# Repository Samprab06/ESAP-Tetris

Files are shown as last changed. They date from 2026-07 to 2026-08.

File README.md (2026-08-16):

# ESAP Tetris

A complete, feature-packed Tetris game implementation for the ESP32 microcontroller featuring a custom PCB design, real-time graphics rendering on an ILI9341 SPI TFT display, I2S audio playback, SD card asset loading and a future multiplayer implementation

---

##  PCB Design

The project features a custom-designed PCB tailored for handheld gameplay with optimized power delivery, hardware debouncing, and an auto-programming USB-C interface.

### Board Renders

| Back View (Component Side) | Front View (Controls) |
| :---: | :---: |
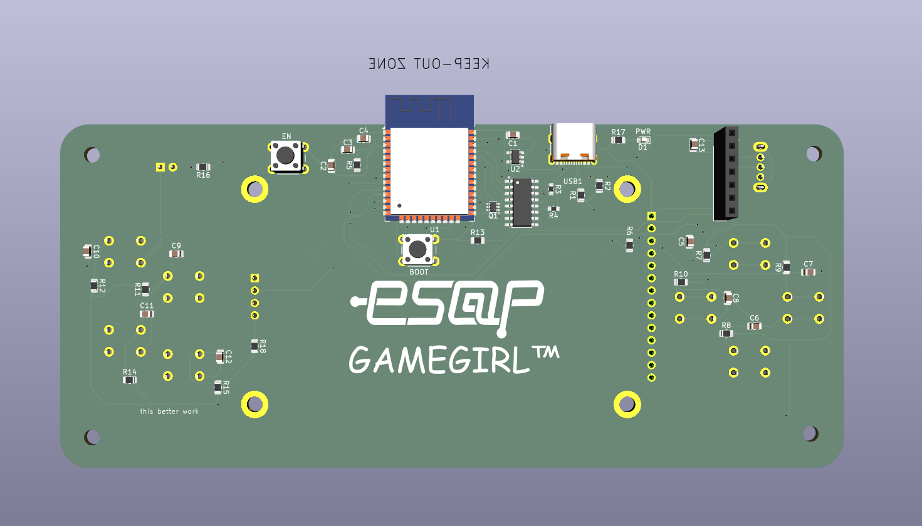
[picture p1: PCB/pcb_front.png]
PCB Front Render
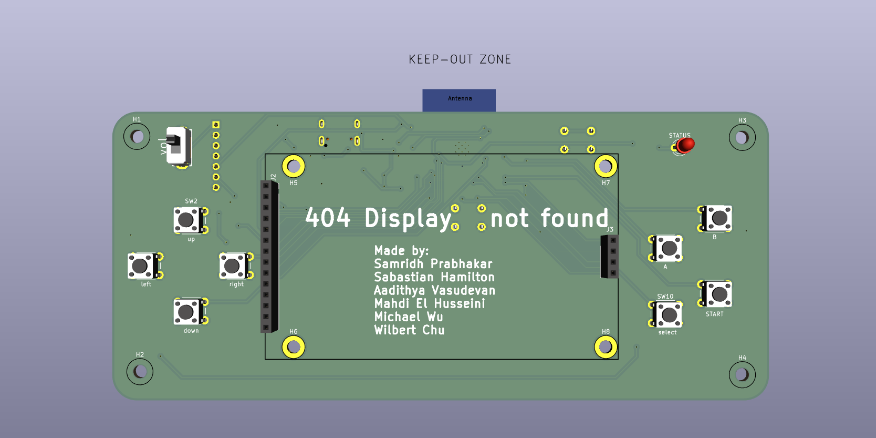
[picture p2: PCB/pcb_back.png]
PCB Back Render
|  |  |

### Key Hardware & Schematic Highlights

- **Microcontroller**: ESP32-WROOM-32 module (32-bit dual-core Xtensa @ 240 MHz, 520 KB SRAM, Wi-Fi/BT).
- **USB-C Interface & Auto-Flashing**: Integrated `CH340C` USB-to-UART converter with dual NPN auto-reset circuitry (`MUN5211DW1`) for seamless hands-free code uploads via USB Type-C.
- **Power Management**: `AP2112K-3.3` LDO regulator supplying up to 600mA at 3.3V with dedicated ground plane thermal heat sinking. USB Type-C `CC1`/`CC2` 5.1kΩ pull-down resistors for 5V C-to-C charger support.
- **Display Connection**: Dedicated 14-pin socket header for 2.8" ILI9341 SPI TFT Display (240×320 resolution) on the `VSPI` bus. Includes 10kΩ pull-up resistor on `CS` (`GPIO5`).
- **SD Card Storage**: 4-pin SPI socket header for MicroSD card module on the `HSPI` bus. Includes 10kΩ pull-up resistor on `CS` (`GPIO15`).
- **Input Controllers**: 8 tactile pushbuttons (UP, DOWN, LEFT, RIGHT, A, B, START, SELECT) with hardware RC debouncing filters (0.1µF capacitors) and 10kΩ pull-up resistors on input-only GPIOs (34, 35, 36, 39).
- **Audio & Volume Control**: Audio output header with an integrated slide switch (`SW12`) for hardware gain/volume control.

---

## 🛠️ Hardware Specifications & Pinout

### SPI Display Connection (VSPI)

| ESP32 Pin | Signal Name | Display Function |
| :--- | :--- | :--- |
| **GPIO 23** | `MOSI` | Serial Data Input |
| **GPIO 19** | `MISO` | Serial Data Output |
| **GPIO 18** | `SCK` | Serial Clock |
| **GPIO 5** | `CS` | Chip Select (10kΩ Pull-Up) |
| **GPIO 2** | `DC` | Data / Command Select |
| **GPIO 4** | `RST` | Reset |
| **3.3V** | `LED` | Display Backlight Power |

### MicroSD Card Connection (HSPI)

| ESP32 Pin | Signal Name | SD Card Function |
| :--- | :--- | :--- |
| **GPIO 13** | `MOSI` | Data Input |
| **GPIO 17** | `MISO` | Data Output |
| **GPIO 14** | `SCK` | Clock |
| **GPIO 15** | `CS` | Chip Select (10kΩ Pull-Up) |

### Game Control Buttons

| GPIO Pin | Function | Hardware Circuit |
| :--- | :--- | :--- |
| **GPIO 36 (VP)** | Left | 10kΩ Pull-Up + 0.1µF Debounce |
| **GPIO 39 (VN)** | Right | 10kΩ Pull-Up + 0.1µF Debounce |
| **GPIO 34** | Down | 10kΩ Pull-Up + 0.1µF Debounce |
| **GPIO 35** | Up / Rotate | 10kΩ Pull-Up + 0.1µF Debounce |
| **GPIO 32** | Button A | 10kΩ Pull-Up + 0.1µF Debounce |
| **GPIO 33** | Button B | 10kΩ Pull-Up + 0.1µF Debounce |
| **GPIO 27** | Start | 10kΩ Pull-Up + 0.1µF Debounce |
| **GPIO 16** | Select | 10kΩ Pull-Up + 0.1µF Debounce |

---

##  Software Architecture

The software is structured as a **PlatformIO** project 

```
ESAP_Tetris/
├── PCB/                     # KiCad 10 PCB schematics, board layouts & gerbers
│   ├── pcb_front.png
│   └── pcb_back.png
├── include/                 # Header files
│   ├── main.hpp
│   ├── logic.h
│   ├── display.h
│   ├── audio.h
│   └── sdcard.h
├── src/                     # Source implementations
│   ├── main.cpp             # FreeRTOS task initialization & main loop
│   ├── logic.cpp            # Tetris game rules & state machine
│   ├── display.cpp          # TFT graphics rendering
│   ├── audio.cpp            # I2S audio decoding & streaming
│   └── sdcard.cpp           # SD card file system interface
├── platformio.ini           # PlatformIO configuration
└── README.md                # Project documentation
```

---

##  Building & Flashing

### Prerequisites
- **VS Code** with **PlatformIO IDE** extension installed.

### Steps
1. Clone the repository:
   ```bash
   git clone https://github.com/Samprab06/ESAP-Tetris.git
   cd ESAP-Tetris
   ```
2. Connect your ESP32 board via USB-C.
3. Build & Upload firmware using PlatformIO:
   ```bash
   pio run -t upload
   ```
4. Open the Serial Monitor:
   ```bash
   pio device monitor
   ```

---

---

##  License

This project is open-source and provided for educational and personal use.

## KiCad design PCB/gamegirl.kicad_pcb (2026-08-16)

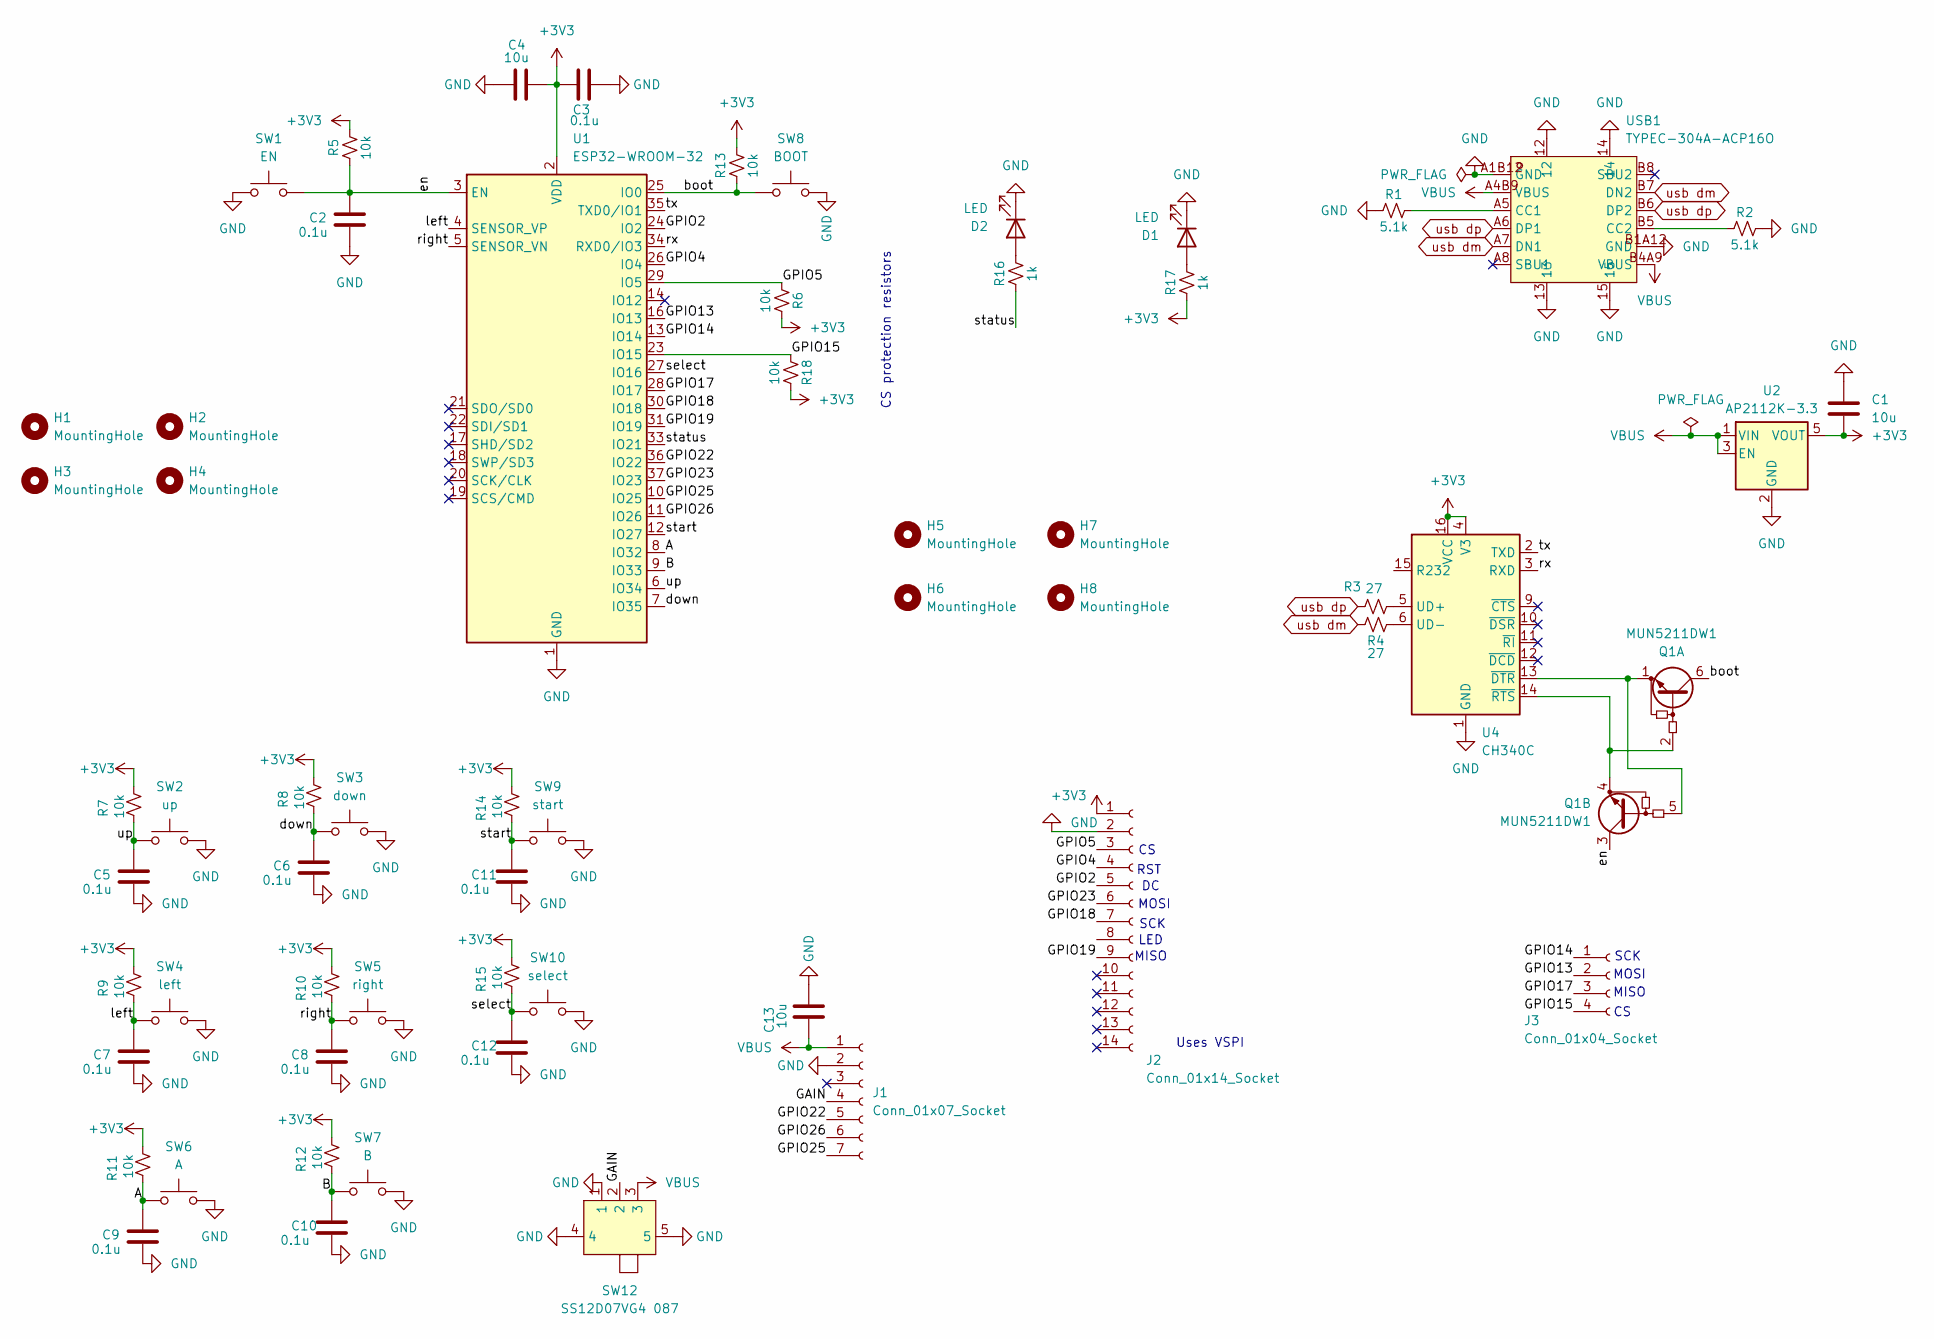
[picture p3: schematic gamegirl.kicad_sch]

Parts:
C1, C4, C13: 10u; C_0805_2012Metric
C2, C3, C5, C6, C7, C8, C9, C10, C11, C12: 0.1u; C_0805_2012Metric
D1, D2: LED; LED_0603_1608Metric
H1, H2, H3, H4: MountingHole; MountingHole_3.2mm_M3
H5, H6, H7, H8: MountingHole; MountingHole_3.2mm_M3_DIN965_Pad
J1: Conn_01x07_Socket; PinSocket_1x07_P2.54mm_Vertical
J2: Conn_01x14_Socket; PinSocket_1x14_P2.54mm_Vertical
J3: Conn_01x04_Socket; PinSocket_1x04_P2.54mm_Vertical
Q1: MUN5211DW1; SOT-363_SC-70-6
R1, R2: 5.1k; R_0805_2012Metric
R3, R4: 27; R_0603_1608Metric
R5, R6, R7, R8, R9, R10, R11, R12, R13, R14, R15, R18: 10k; R_0805_2012Metric
R16, R17: 1k; R_0805_2012Metric
SW1: EN; SW_PUSH_6mm
SW2: up; SW_PUSH_6mm
SW3: down; SW_PUSH_6mm
SW4: left; SW_PUSH_6mm
SW5: right; SW_PUSH_6mm
SW6: A; SW_PUSH_6mm
SW7: B; SW_PUSH_6mm
SW8: BOOT; SW_PUSH_6mm
SW9: start; SW_PUSH_6mm
SW10: select; SW_PUSH_6mm
SW12: SS12D07VG4 087; SW-TH_SS12D07VG4; MPN SS12D07VG4 087; LCSC Part C2939726
U1: ESP32-WROOM-32
U2: AP2112K-3.3; SOT-23-5
U4: CH340C; SOIC-16_3.9x9.9mm_P1.27mm
USB1: TYPEC-304A-ACP16O; USB-SMD_TYPEC-304A-ACP16O; MPN TYPEC-304A-ACP16O; LCSC Part C2909610

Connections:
+3V3: C1.2, C3.1, C4.2, J2.1, R5.2, R6.2, R7.2, R8.2, R9.2, R10.2, R11.2, R12.2, R13.2, R14.2, R15.2, R17.1, R18.2, U1.2 (VDD), U2.5 (VOUT), U4.4 (V3), U4.16 (VCC)
/A: C9.1, R11.1, SW6.1, U1.8 (IO32)
/B: C10.1, R12.1, SW7.1, U1.9 (IO33)
/GAIN: J1.4, SW12.2
/GPIO2: J2.5, U1.24 (IO2)
/GPIO4: J2.4, U1.26 (IO4)
/GPIO5: J2.3, R6.1, U1.29 (IO5)
/GPIO13: J3.2, U1.16 (IO13)
/GPIO14: J3.1, U1.13 (IO14)
/GPIO15: J3.4, R18.1, U1.23 (IO15)
/GPIO17: J3.3, U1.28 (IO17)
/GPIO18: J2.7, U1.30 (IO18)
/GPIO19: J2.9, U1.31 (IO19)
/GPIO22: J1.5, U1.36 (IO22)
/GPIO23: J2.6, U1.37 (IO23)
/GPIO25: J1.7, U1.10 (IO25)
/GPIO26: J1.6, U1.11 (IO26)
/boot: Q1.6 (C1), R13.1, SW8.1, U1.25 (IO0)
/down: C6.1, R8.1, SW3.1, U1.7 (IO35)
/en: C2.1, Q1.3 (C2), R5.1, SW1.2, U1.3 (EN)
/left: C7.1, R9.1, SW4.1, U1.4 (SENSOR_VP)
/right: C8.1, R10.1, SW5.1, U1.5 (SENSOR_VN)
/rx: U1.34 (RXD0/IO3), U4.3 (RXD)
/select: C12.1, R15.1, SW10.1, U1.27 (IO16)
/start: C11.1, R14.1, SW9.1, U1.12 (IO27); also elsewhere on the board
/status: R16.1, U1.33 (IO21)
/tx: U1.35 (TXD0/IO1), U4.2 (TXD)
/up: C5.1, R7.1, SW2.1, U1.6 (IO34)
GND: C1.1, C2.2, C3.2, C4.1, C5.2, C6.2, C7.2, C8.2, C9.2, C10.2, C11.2, C12.2, C13.2, D1.1 (K), D2.1 (K), J1.2, J2.2, R1.1, R2.2, SW1.1, SW2.2, SW3.2, SW4.2, SW5.2, SW6.2, SW7.2, SW8.2, SW9.2, SW10.2, SW12.1, SW12.4, SW12.5, U1.1 (GND), U1.15 (GND), U1.38 (GND), U1.39 (GND), U2.2 (GND), U4.1 (GND), USB1.12, USB1.13, USB1.14, USB1.15, USB1.A1B12 (GND), USB1.B1A12 (GND); also elsewhere on the board
unnamed: D1.2 (A), R17.2
unnamed: D2.2 (A), R16.2
unnamed: Q1.2 (B1), Q1.4 (E2), U4.14 (~RTS)
unnamed: Q1.1 (E1), Q1.5 (B2), U4.13 (~DTR)
unnamed: R3.2, U4.5 (UD+)
unnamed: R4.2, U4.6 (UD-)
unnamed: R1.2, USB1.A5 (CC1)
unnamed: R2.1, USB1.B5 (CC2)
VBUS: C13.1, J1.1, SW12.3, U2.1 (VIN), U2.3 (EN), USB1.A4B9 (VBUS), USB1.B4A9 (VBUS)
usb dm: R4.1, USB1.A7 (DN1), USB1.B7 (DN2)
usb dp: R3.1, USB1.A6 (DP1), USB1.B6 (DP2)

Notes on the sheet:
MISO
SCK
CS protection resistors
Uses VSPI
MOSI
LED
RST

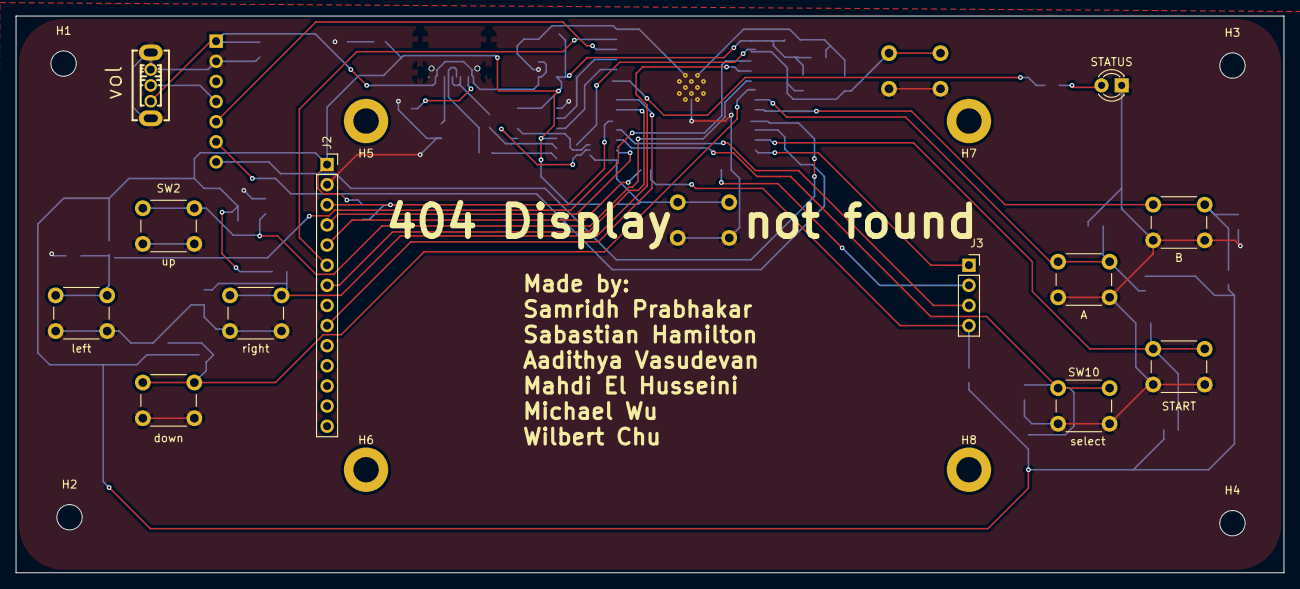
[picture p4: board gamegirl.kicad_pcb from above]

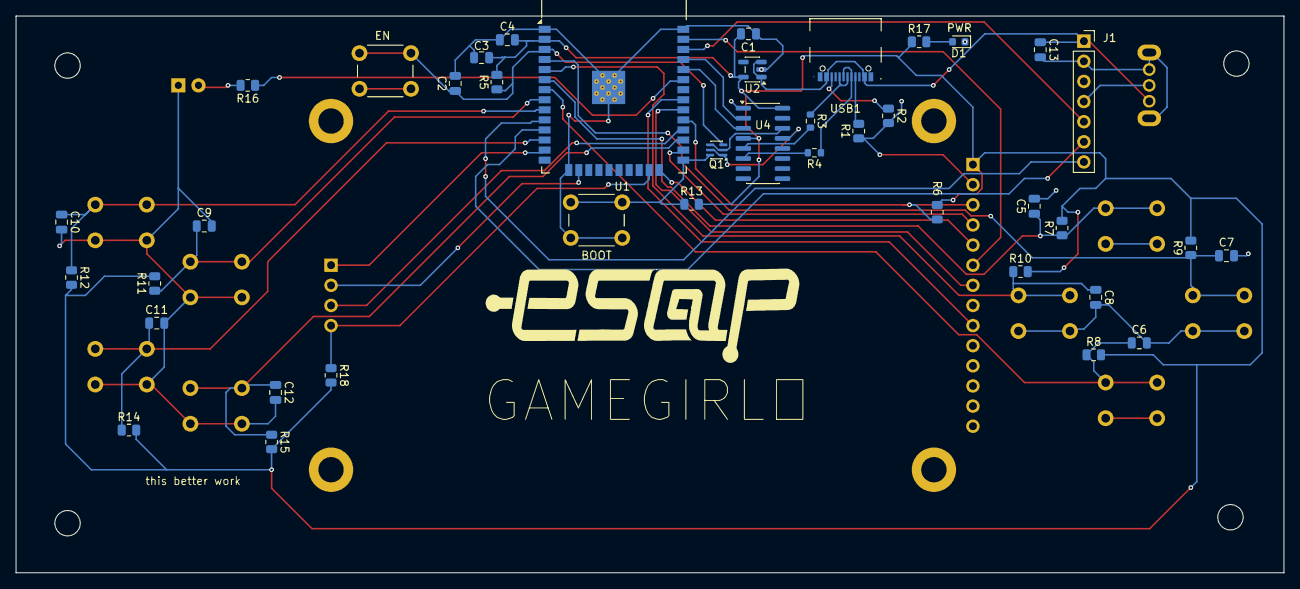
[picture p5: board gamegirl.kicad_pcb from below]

Board: 2 copper layers, 160.0 x 70.2 mm, 60 parts (40 on the bottom side), 40 nets.

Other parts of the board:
START: start; SW_PUSH_6mm

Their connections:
/start: START.1; also elsewhere on the board
GND: START.2; also elsewhere on the board

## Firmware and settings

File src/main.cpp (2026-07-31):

#include "main.hpp"

SPIClass hspi(HSPI);

void audioTask(void *pvParameters)
{
    printf("Audio task started on core %d\n", xPortGetCoreID());

    // sd card read through hspi
    hspi.begin(14, 12, 13, 15);

    if (!SD.begin(15, hspi))
    {
        printf("Card Mount Failed\n");
        return;
    }

    uint8_t cardType = SD.cardType();
    if (cardType == CARD_NONE)
    {
        printf("No SD card attached\n");
        return;
    }

    // File path
    audioFile = SD.open("/tetris.wav");
    if (!audioFile || audioFile.isDirectory())
    {
        printf("Failed to open WAV file\n");
    }
    else
    {
        audioFile.seek(44);
        printf("File opened, ready to stream\n");
    }

    // i2s audio
    // still need to verify the pins
    I2S.setPins(26, 25, 22, -1, -1);

    if (!I2S.begin(I2S_MODE_STD, 44100, I2S_DATA_BIT_WIDTH_16BIT, I2S_SLOT_MODE_MONO))
    {
        // Handle initialization failure
        vTaskDelete(NULL);
    }

    while (true)
    {
        playWav();
        vTaskDelay(1);
    }
}

void setup()
{
    Serial.begin(115200);

    // display
    tft.init();
    tft.setRotation(3);
    tft.fillScreen(TFT_BLACK);

    pinMode(PIN_LEFT, INPUT);
    pinMode(PIN_RIGHT, INPUT);
    pinMode(PIN_DOWN, INPUT);
    pinMode(PIN_ROT, INPUT);
    pinMode(PIN_START, INPUT);

    randomSeed(esp_random());
    init_state(&gameState);

    gameState.paused = true;
    drawUI(&gameState);

    xTaskCreatePinnedToCore(
        audioTask,
        "AudioTask",
        10000,
        NULL,
        2,
        NULL,
        0);
}

void loop()
{
    unsigned long currentMillis = millis();
    bool currStart = (digitalRead(PIN_START) == ACTIVE_STATE);

    // --- Start/Pause/Restart Logic ---
    if (currStart && !lastStart)
    {
        if (!gameState.alive)
        {
            // Restart game if dead
            tft.fillScreen(TFT_BLACK);
            init_state(&gameState);
            gameState.paused = false;
        }
        else
        {
            // Toggle pause if alive
            gameState.paused = !gameState.paused;
            if (gameState.paused)
            {
                tft.setTextColor(TFT_YELLOW, TFT_BLACK);
                tft.drawCentreString("PAUSED", 160, 110, 4);
            }
            else
            {
                // Clear the "PAUSED" text when unpausing
                tft.fillRect(100, 100, 120, 40, TFT_BLACK);
            }
        }
    }
    lastStart = currStart;

    if (!gameState.paused && gameState.alive)
    {
        // --- DAS Input Logic (Left/Right) ---
        bool currL = (digitalRead(PIN_LEFT) == ACTIVE_STATE);
        bool currR = (digitalRead(PIN_RIGHT) == ACTIVE_STATE);

        // Left DAS
        if (currL)
        {
            if (lPressTime == 0)
            {
                gameInput.L = 1;
                lPressTime = currentMillis;
                lDasActive = false;
            }
            else if (!lDasActive && (currentMillis - lPressTime >= DAS_DELAY))
            {
                gameInput.L = 1;
                lPressTime = currentMillis;
                lDasActive = true;
            }
            else if (lDasActive && (currentMillis - lPressTime >= ARR_DELAY))
            {
                gameInput.L = 1;
                lPressTime = currentMillis;
            }
            else
            {
                gameInput.L = 0;
            }
        }
        else
        {
            gameInput.L = 0;
            lPressTime = 0;
            lDasActive = false;
        }

        // Right DAS
        if (currR)
        {
            if (rPressTime == 0)
            {
                gameInput.R = 1;
                rPressTime = currentMillis;
                rDasActive = false;
            }
            else if (!rDasActive && (currentMillis - rPressTime >= DAS_DELAY))
            {
                gameInput.R = 1;
                rPressTime = currentMillis;
                rDasActive = true;
            }
            else if (rDasActive && (currentMillis - rPressTime >= ARR_DELAY))
            {
                gameInput.R = 1;
                rPressTime = currentMillis;
            }
            else
            {
                gameInput.R = 0;
            }
        }
        else
        {
            gameInput.R = 0;
            rPressTime = 0;
            rDasActive = false;
        }

        // Rotate and Down
        bool currRot = (digitalRead(PIN_ROT) == ACTIVE_STATE);
        gameInput.Z = (currRot && !lastRot) ? 1 : 0;
        gameInput.D = (digitalRead(PIN_DOWN) == ACTIVE_STATE);
        lastRot = currRot;

        update(&gameState, &gameInput);
        drawGame(&gameState);
    }
    else if (!gameState.alive)
    {
        tft.setTextColor(TFT_RED, TFT_BLACK);
        tft.drawCentreString("GAME OVER", 160, 100, 4);
        tft.drawCentreString("Press START to Reset", 160, 140, 2);
    }

    drawUI(&gameState);
    delay(16);
}

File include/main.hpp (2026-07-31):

#pragma once

#include <SPI.h>
#include <ESP_I2S.h>
#include "sdcard.h"
#include "display.h"
#include "logic.h"
#include "audio.h"
#include "globals.hpp"
// #include <ESP_NOW.h>

// pin Definitions
#define PIN_DOWN 34
#define PIN_ROT 35
#define PIN_LEFT 36
#define PIN_RIGHT 39
#define PIN_START 32
#define ACTIVE_STATE HIGH

// delay for how long to hold down button to trigger auto move
#define DAS_DELAY 250
#define ARR_DELAY 50

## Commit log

2026-04-12 added start button fixed text not working
2026-04-13 Force track arduino-esp32 directory
2026-07-31 fix more lib errors, carry over readme
    [main.hpp]
2026-08-16 final changes
    [gamegirl-CuBottom.gbr, gamegirl-CuTop.gbr, gamegirl-EdgeCuts.gbr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]
